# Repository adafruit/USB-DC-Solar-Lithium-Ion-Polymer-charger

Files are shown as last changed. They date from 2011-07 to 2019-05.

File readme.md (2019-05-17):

# Adafruit USB/DC/Solar LiIon/LiPoly charger

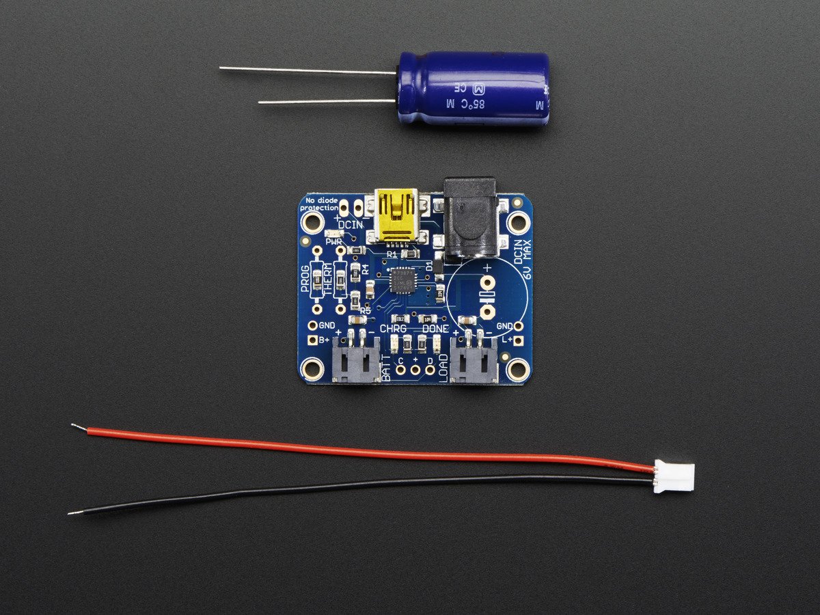
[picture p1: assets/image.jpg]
<a href="http://www.adafruit.com/products/390"><br/>
Click here to purchase one from the Adafruit shop</a>

NOTE: This product is only designed for use with solar panels sold at the Adafruit store. We cannot guarantee this will work with solar panels purchased elsewhere. Please purchase this kit and panels from Adafruit to ensure optimized functionality! A 2.1mm adapter cable is also required to adapt a solar panel to the DC power jack.

Make your projects to go green this summer with our specialized USB/Solar Lithium Ion Polymer Battery charger! This charger is a very unique design, perfect for outdoor projects, or DIY iPod chargers. We've spent over a year testing and tinkering with this charger to come up with a plug and play solution to charging batteries with the sun and we're really pleased with what we ended up with.

Easy to use! Pick up any of our many 3.7V/4.2V LiIon batteries, and a 6V solar panel. Plug the battery into the BATT port using a 2-pin JST cable and the solar panel into the DC jack using a 2.1mm adapter cable Put the solar panel outside (and keep the battery out of the sun, it needs to be kept cool!) to start charging. You can power another project like a Mintyboost at the same time by connecting to the LOAD output port

This repo contains the Eagle CAD files for the Adafruit USB/DC/Solar LiIon/LiPoly charger https://www.adafruit.com/product/390

### License

Adafruit invests time and resources providing this open source design, please support Adafruit and open-source hardware by purchasing products from [Adafruit](https://www.adafruit.com)!

All text above must be included in any redistribution

Designed by Limor Fried/Ladyada for Adafruit Industries.
Creative Commons Attribution/Share-Alike, all text above must be included in any redistribution. 
See license.txt for additional information.

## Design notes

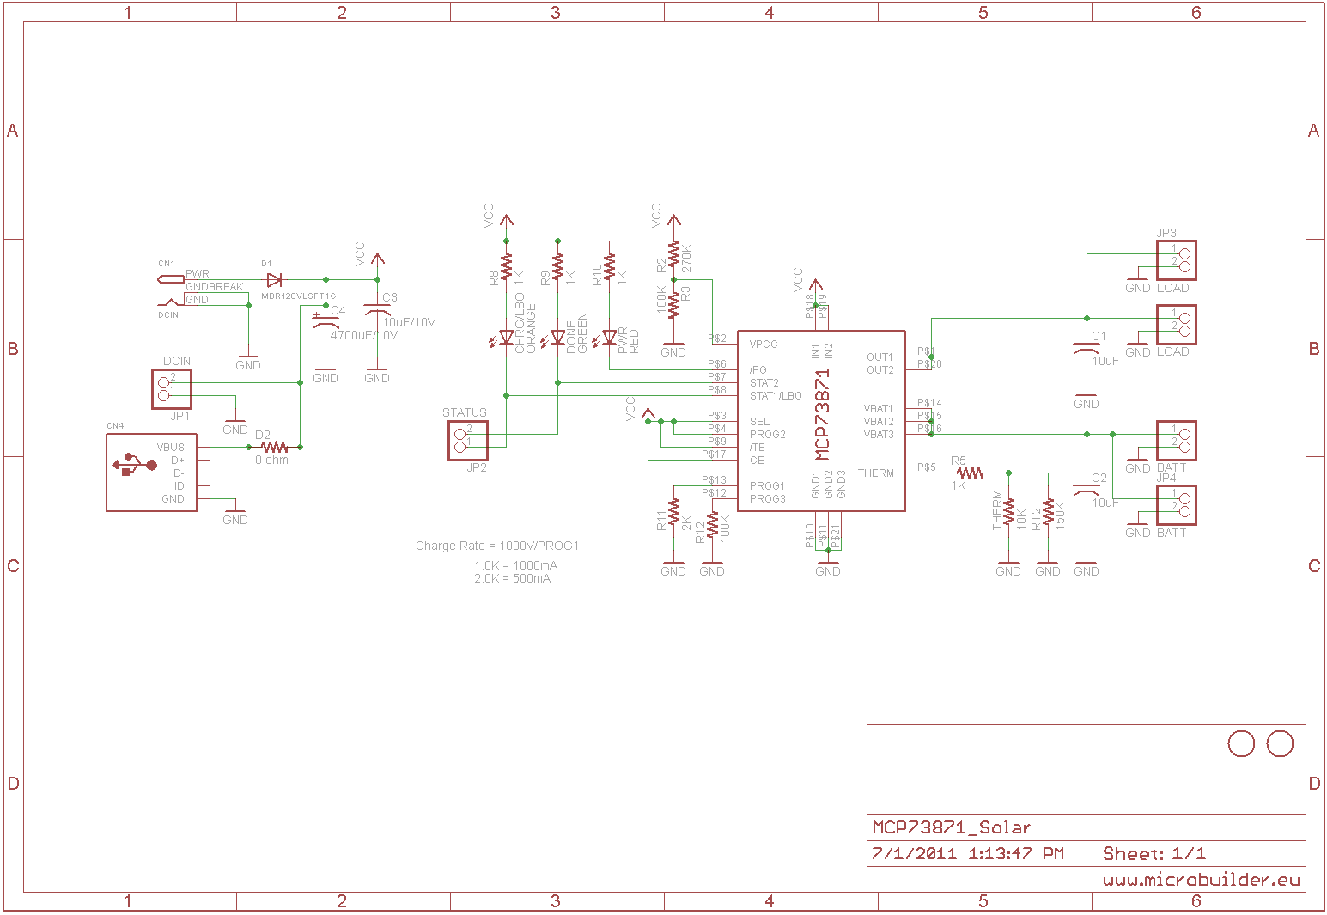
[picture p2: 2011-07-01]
schem.png

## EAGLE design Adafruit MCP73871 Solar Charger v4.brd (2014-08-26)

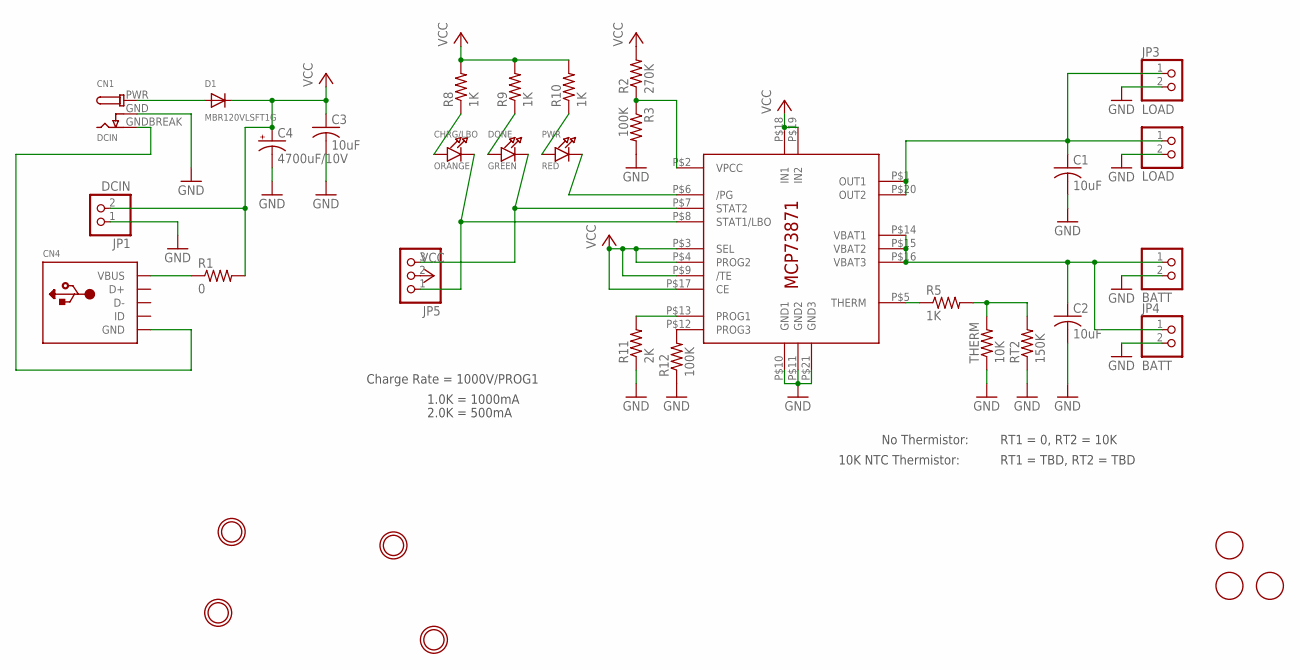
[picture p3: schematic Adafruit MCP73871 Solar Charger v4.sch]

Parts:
BATT: JST_2PIN-SMT-RA; JST-PH-2-SMT-RA
C1, C2, C3: 10uF; C0805K
C4: 4700uF/10V; E5-13
CHRG/LBO: ORANGE; CHIPLED_0805_NOOUTLINE
CN1: DCIN; DCJACK_2MM_SMT
CN4: USBMINIBLARGE; USB-MINIB_LARGER
D1: MBR120VLSFT1G; SOD-123
DONE: GREEN; CHIPLED_0805_NOOUTLINE
IC1: MCP73871; QFN20_4MM
JP1: DCIN; 1X02_OVAL
JP3: LOAD; 1X02_ROUND
JP4: BATT; 1X02_ROUND
JP5: PINHD-1X3CB; 1X03-CLEANBIG
LOAD: JST_2PIN-SMT-RA; JST-PH-2-SMT-RA
PWR: RED; CHIPLED_0805_NOOUTLINE
R1: 0; R0805
R2: 270K; R0805
R3, R12: 100K; R0805
R5: 1K; M0805
R8, R9, R10: 1K; R0805
R11: 2K; 0805-THM
RT2: 150K; M0805
THERM: 10K; 0805-THM
U$2, U$3, U$8: FIDUCIAL; FIDUCIAL_1MM
U$4, U$5, U$6, U$7: MOUNTINGHOLE2.5; MOUNTINGHOLE_2.5_PLATED

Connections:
BATT: BATT.1 (2), C2.1, IC1.P$14 (VBAT1), IC1.P$15 (VBAT2), IC1.P$16 (VBAT3), JP4.1
GND: BATT.2 (1), C1.2, C2.2, C3.2, C4.-, CN1.GND (GNDBREAK), IC1.P$10 (GND1), IC1.P$11 (GND2), IC1.P$21 (GND3), JP1.1, JP3.2, JP4.2, LOAD.2 (1), R3.2, R11.1, R12.1, RT2.1, THERM.1
unnamed: IC1.P$6 (/PG), PWR.C
unnamed: CN4.VBUS, R1.1
unnamed: CN1.GNDBREAK (GND), CN4.GND, CN4.GND1 (GND), CN4.GND2 (GND), CN4.GND3 (GND), CN4.GND4 (GND)
unnamed: DONE.C, IC1.P$7 (STAT2), JP5.3
unnamed: IC1.P$5 (THERM), R5.1
unnamed: IC1.P$2 (VPCC), R2.1, R3.1
unnamed: R5.2, RT2.2, THERM.2
unnamed: CN1.PWR, D1.A
unnamed: CHRG/LBO.C, IC1.P$8 (STAT1/LBO), JP5.1
unnamed: CHRG/LBO.A, R8.1
unnamed: DONE.A, R9.1
unnamed: PWR.A, R10.1
unnamed: IC1.P$12 (PROG3), R12.2
unnamed: IC1.P$13 (PROG1), R11.2
OUT: C1.1, IC1.P$1 (OUT1), IC1.P$20 (OUT2), JP3.1, LOAD.1 (2)
VCC: C3.1, C4.+, D1.C, IC1.P$3 (SEL), IC1.P$4 (PROG2), IC1.P$9 (/TE), IC1.P$17 (CE), IC1.P$18 (IN1), IC1.P$19 (IN2), JP1.2, JP5.2, R1.2, R2.2, R8.2, R9.2, R10.2

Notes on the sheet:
Charge Rate = 1000V/PROG1
1.0K = 1000mA
2.0K = 500mA
No Thermistor:
10K NTC Thermistor:
RT1 = 0, RT2 = 10K
RT1 = TBD, RT2 = TBD

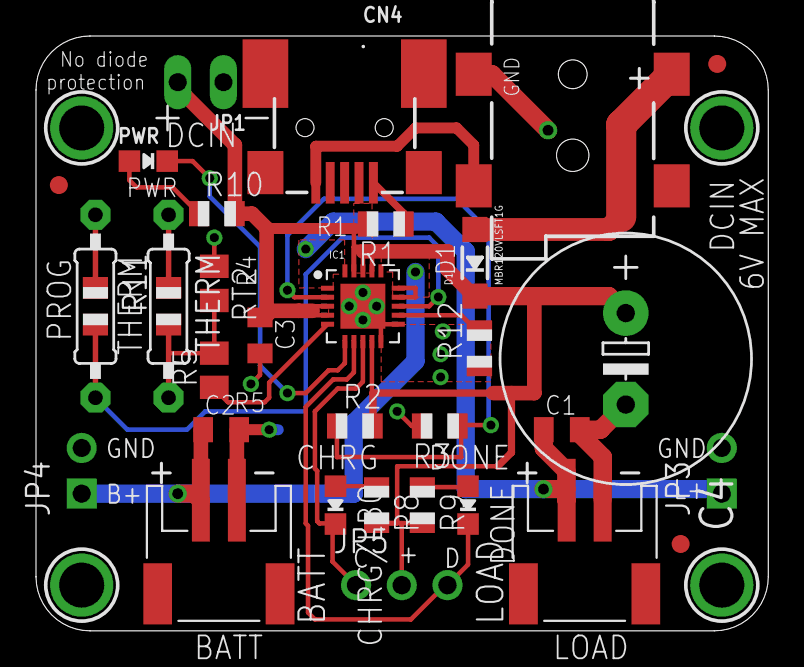
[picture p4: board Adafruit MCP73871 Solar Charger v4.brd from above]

Board: 2 copper layers, 40.7 x 33.0 mm, 36 parts (1 on the bottom side), 18 nets.

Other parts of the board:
U$1: ADAFRUIT_TEXT_20MM

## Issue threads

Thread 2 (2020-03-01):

airwires exist on the board

netskink, 2020-03-01:
When you run the ratsnest command, the board file for the version 4 board has four air wires. Isn't that a problem? See photo for airwires between GND4 N$3 and GND3 N$3 for example.
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

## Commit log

2011-07-01 Initial commit of release
    [MCP73871_Solar.brd, MCP73871_Solar.sch]
2014-08-26 latest rev!
    [Adafruit MCP73871 Solar Charger v4.brd, Adafruit MCP73871 Solar Charger v4.sch]
